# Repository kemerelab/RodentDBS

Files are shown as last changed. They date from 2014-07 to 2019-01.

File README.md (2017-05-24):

Rodent Stimulation Module Project
=========

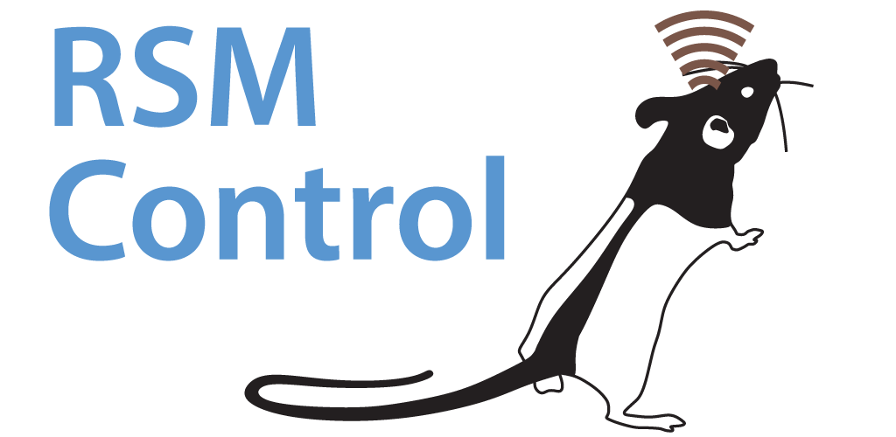
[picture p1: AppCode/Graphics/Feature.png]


Rodent-scale open source programmable constant current deep brain stimulation system. Runs on a
low power MSP430 microcontroller from Texas Instrumnents. Interfaces with an Android app using
Near Field Communication (NFC).

   - The [Firmware/](Firmware/) directory contains the code which runs on the MSP430. 
   - The [AppCode/](AppCode/) directory contains the Android Studio project and code for the
     NFC controller app.
   - The [PCBs/](PCBs/) directory contains the design files for the printed circuit board
     hardware.

#### Physical Size of Devices In Action
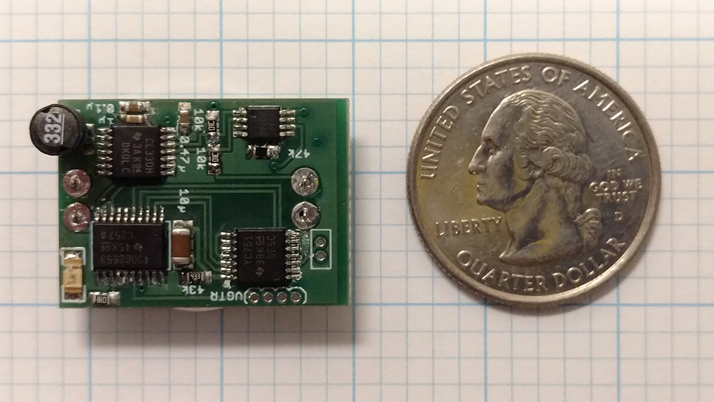
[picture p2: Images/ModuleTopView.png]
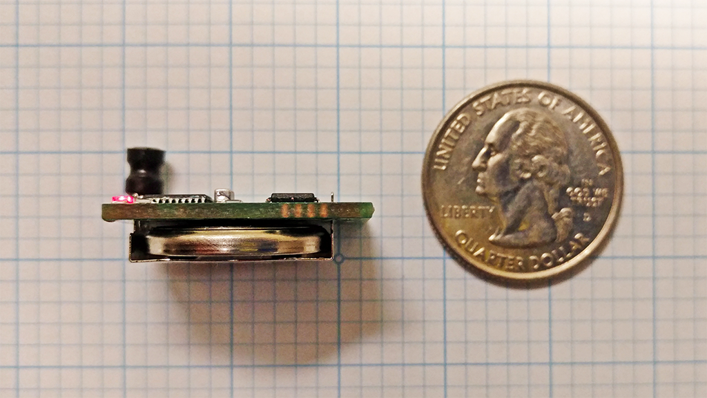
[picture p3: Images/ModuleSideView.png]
 

The most recent version of the hardware is about 1/4" thick including a CR2032 battery, and a
little larger than a quarter in footprint. Battery life is about 200 hours. In photos above,
major grid is 1/2".

#### Biphasic Constant Current Stimulation
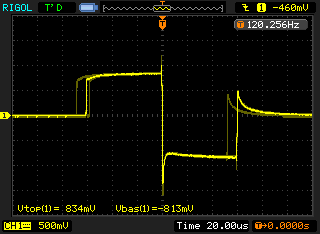
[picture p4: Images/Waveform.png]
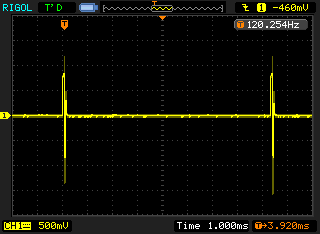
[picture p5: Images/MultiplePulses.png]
 

Current measurements (voltage over the series 10 K resistor)
for a 90 µA, 60 µs, 120 Hz stimulation settings.

Developed by members of the [Kemere Lab](http://rnel.rice.edu) at Rice University. This work
was supported by the National Science Foundation (NSF CAREER Award CBET-1351692) and Texas
Instruments, Inc. Any opinions, findings, and conclusions or recommendations expressed in this
material are those of the author(s) and do not necessarily reflect the views of the National
Science Foundation.



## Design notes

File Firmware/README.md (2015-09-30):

### Firmware for the Rodent Stimulation Module Project

The most recent version of the firmware is [FirmwareCode/](FirmwareCode/). Firmware
for older, non NFC-controlled devices is in [Old_NoNFC/](Old_NoNFC).
[BoardTest/](BoardTest/) is a simple program which blinks the LED to test whether the
MSP430 is programming correctly (in the future, we'll add tests of the other devices on board
to this code).

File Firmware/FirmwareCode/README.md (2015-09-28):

## Overview

The firmware runs on an MSP430G2553. This is a low power TI microcontroller. 

## Estimating power consumption 

**MSP430**
In sleep mode, we can only go to LPM0 because the stimulation counter is using 
the DCO to generate a 1 MHz SMCLK. Unclear is how often we are in active mode.

   - Active power  = ~70 uA
   - Sleep (LPM0) = ~35 uA

**Battery voltage sampling**
The MSP430 ADC10 will consume something like 800 uA when it's turned on, but we sample only
once per minute, so expect not to have significant contribution to power consumption.

**I2C current**
I2C pullup resistors should not be causing signifant current use as I/Os should be high-Z
except during data transmission.

**Power LED**
We're using PWM and flashing, so we're active for only PWM rate * On time.  An on PWM level of
20% and a 25 ms flash every second implies a scaling of 0.2 * 0.025 = 0.005. If VDD is 3 V, and
the on voltage of the (red) LED is 1.8 V, with a 1 K current limiting resistor, our on current
is 1.2 mA. So expect consumption is 6 uA.

   - LED power = 6 uA

**DS4432**
Unfortunately, the current source has to be on all the time because turning on and off would
essentially take the entire inter-pulse period (due to I2C transmission time). Hard to tell
from the data sheet exactly what power will be. Max is 150 uA, but we expect a bit less.

   - DS4432 power = 100 uA

**TS3A4751** (switch matrix)
The switch matrix is fairly efficient, though it, like the DS4432, is powered constantly. We
expect supply current to be close to 3.6 V table values.

  - TS3A4751 power = 1 uA

**RF430** (NFC power)
The RF430 will actually work much better with a 3V supply than a 3.6V supply because the NFC
field provides a 3V power source. In that regime, using NFC to read data is essentially free,
and only during periods when the device is communicating with the MSP430 does it consume power.
When we read data, we are read/writing in the following pattern:
  (1) check status (i.e., address  + 2 bytes = 2 bytes)
  (2) potentially clear interrupts (address + 4 bytes = 5 bytes)
  (3) disable RF (address + 4 bytes = 5 bytes)
  (4) read stim parameters (address + 2 + 6 = 9 bytes)
  (5) re-enable RF (5 bytes)
This is a total of ~26 bytes worth of I2C at 400 kHz, which corresponds to 520 us.
Writing is the same except that the data transmission stage is 21 instead of 6 bytes, so 820
us. Currently, the firmware is set to write 3x/second and read once per 30 seconds or on
demand. So that suggests that the device will be active for 2.5 ms per second. Active power is
250 uA and "passive" power is 40 uA (though we could lower to 15 uA by disabling RF). So we
expect passive mode to dominate, or ~40 uA consumption.

  - RF430 power = 40 uA

  - Total power assuming active mode dominates for MS430 = 217 uA
  - Total power assuming passive mode dominates for MS430 = 182 uA

According to Energizer, we can expect a CR2032 to drop below 2.7 V (the rated minimum voltage
for the DS4432 current source) after about 1000 hours at a constant draw of 0.19 mA. So we
expect our battery life to be ~900 hours, which would be a month. However, in practice, we're
seeing something less than that!?

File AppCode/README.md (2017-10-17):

### RSMControl - An Android app for controlling the Rodent Stimulation Moduke using NFC

### Screenshots

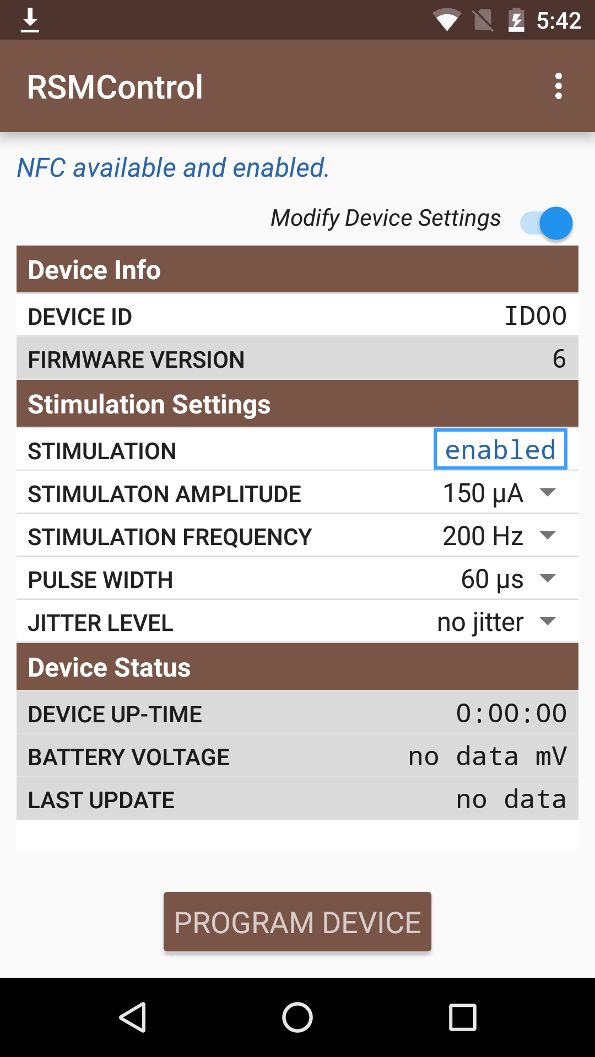
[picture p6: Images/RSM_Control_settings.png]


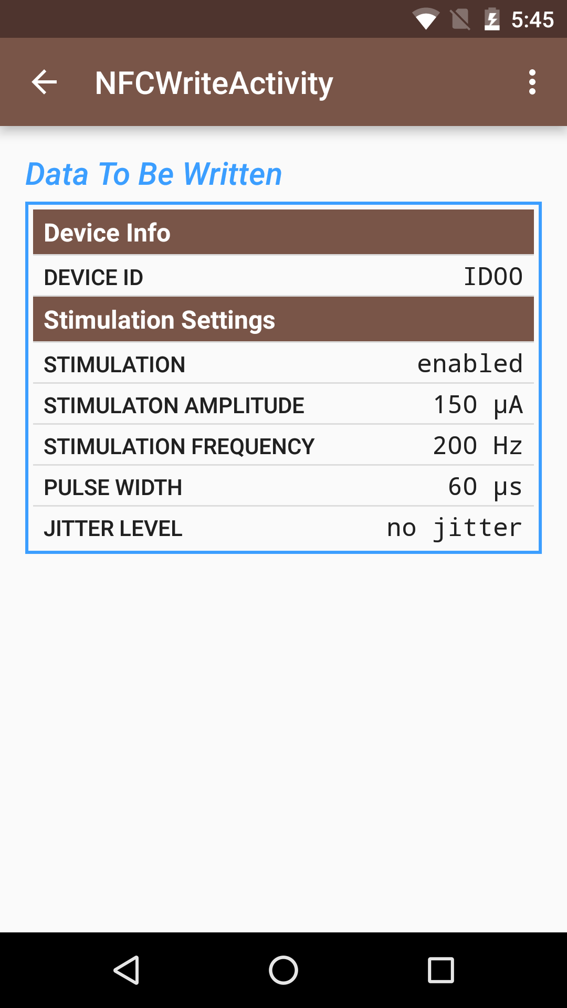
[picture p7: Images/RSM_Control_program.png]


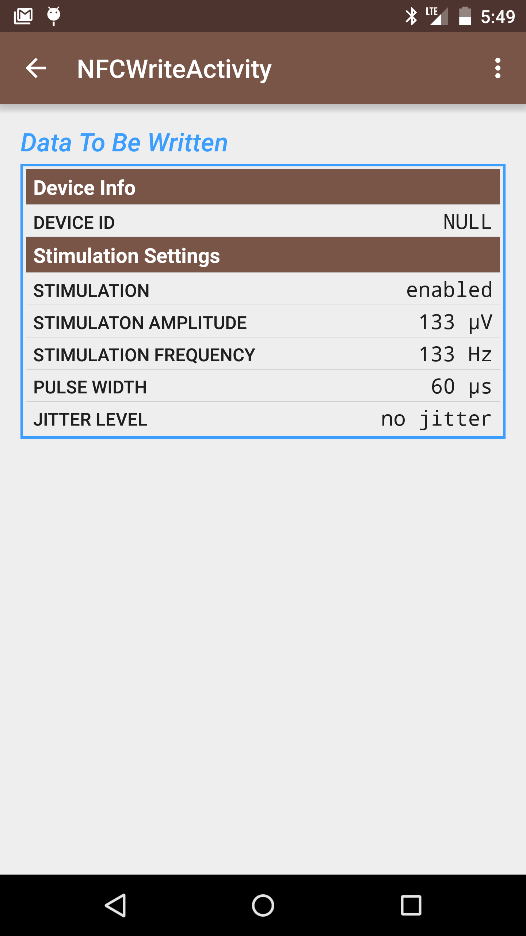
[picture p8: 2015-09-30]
AppCode/Graphics/AndroidAppScreenshot2.png

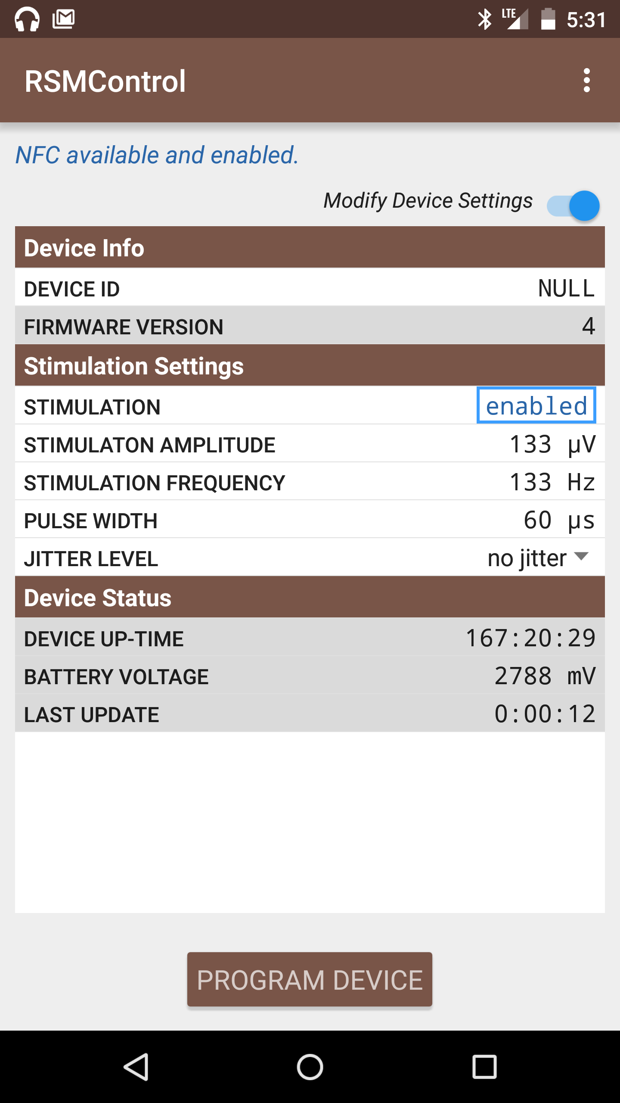
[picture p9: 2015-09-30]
AppCode/Graphics/AndroidAppScreenshot.png

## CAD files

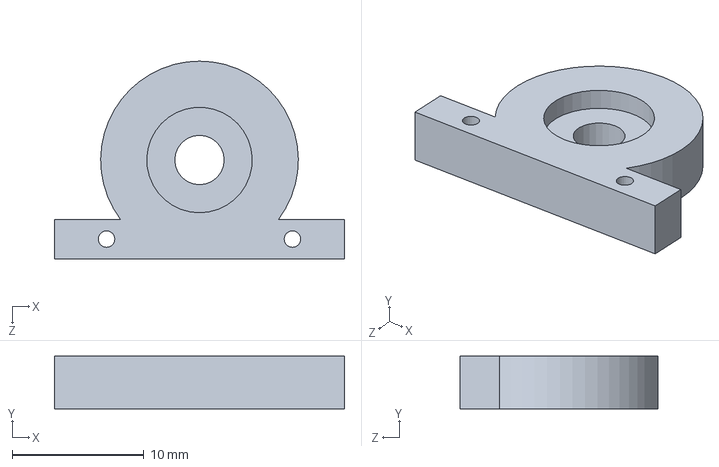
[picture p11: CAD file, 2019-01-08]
Headcap Assembly Files/cone_stereotax_adapter.SLDPRT
22.0 x 4.00 x 15.0 mm

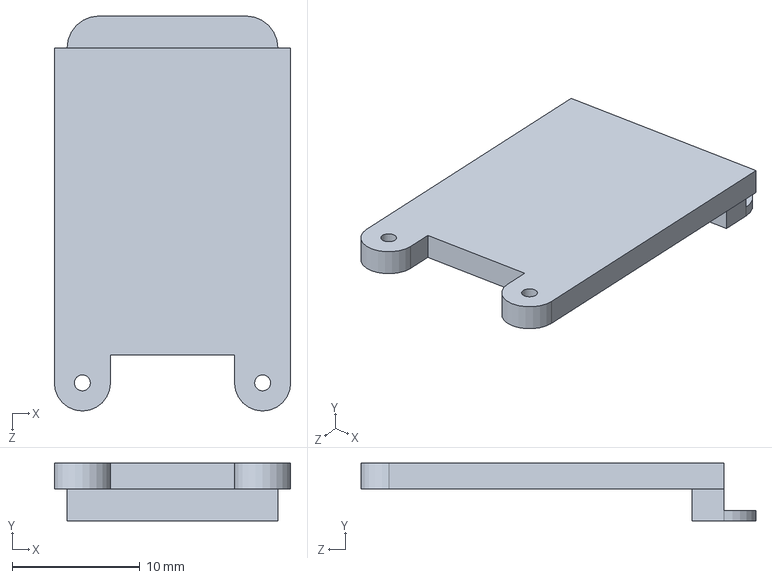
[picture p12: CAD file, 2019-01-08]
Headcap Assembly Files/lid_no_stimulator.SLDPRT
18.5 x 4.50 x 30.9 mm

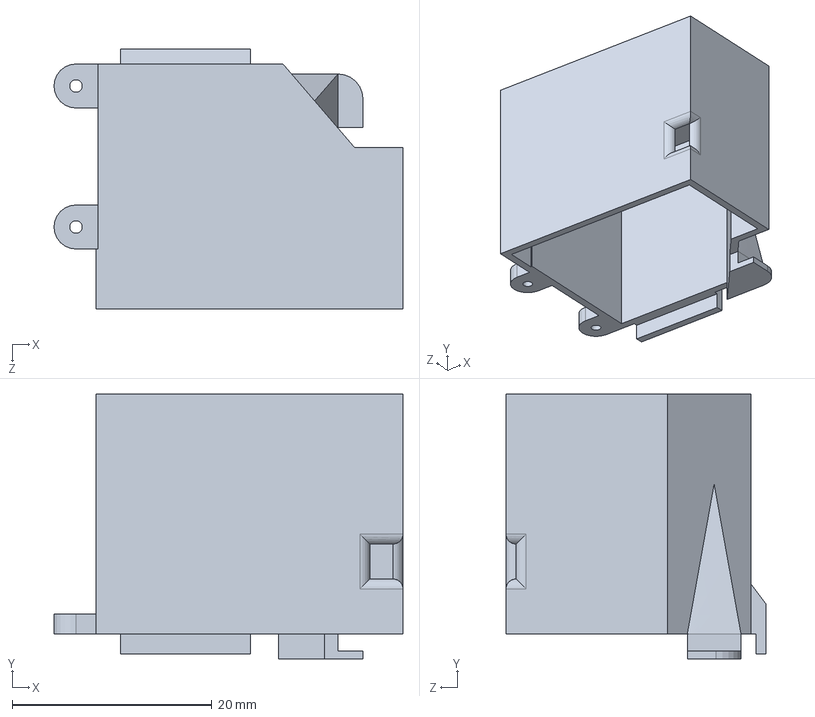
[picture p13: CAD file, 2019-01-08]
Headcap Assembly Files/lid_for_stimulator.SLDPRT
34.9 x 26.5 x 26.0 mm

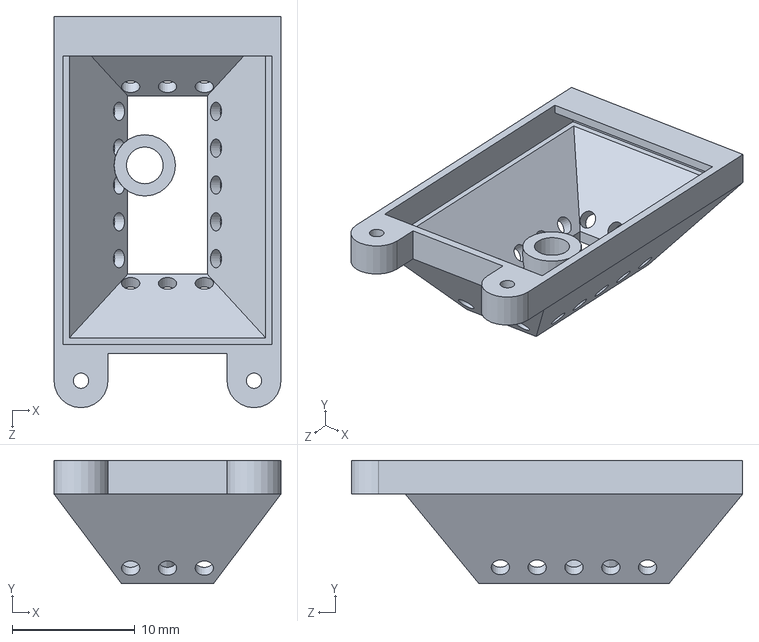
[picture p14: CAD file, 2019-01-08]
Headcap Assembly Files/plastics_one_concentric_cone.SLDPRT
18.5 x 10.0 x 31.9 mm

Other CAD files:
Headcap Assembly Files/cone_stereotax_adapter.STL
Headcap Assembly Files/lid_for_stimulator.STL
Headcap Assembly Files/lid_no_stimulator.STL
Headcap Assembly Files/plastics_one_concentric_cone.STL

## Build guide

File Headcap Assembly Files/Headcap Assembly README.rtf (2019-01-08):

Mounting the stimulator to the rodent consists of 2 parts there is a cone that is attached to the rodent skull, and a lid that will cover the electrode ports of the cone, or hold the stimulator. The cone fits a plastics one concentric 22 gauge 2 channel electrode.

The shaft for the cone must be tapped with an 8-32 thread to fit fit the electrode. The electrode is fixed to the cone body by superglue in the threading to keep the electrode from shifting while disconnecting and reconnecting the plastics one electrode adapter.

The cone electrode assembly is lowered stereotaxically using the stereotax adapter. 0-80 screws attach the adapter to the cone. The adapter screws into the arm of the stereotax. The cone is fixed to the rodent skull with dental acryllic, bone screws, and bone cement.

The stimulator printed circuit board fits vertically into the lid with the inductive NFC antennae towards the top of the lid for programming. The assembly with electrode, lid, and circuit board are illustradted in the render.

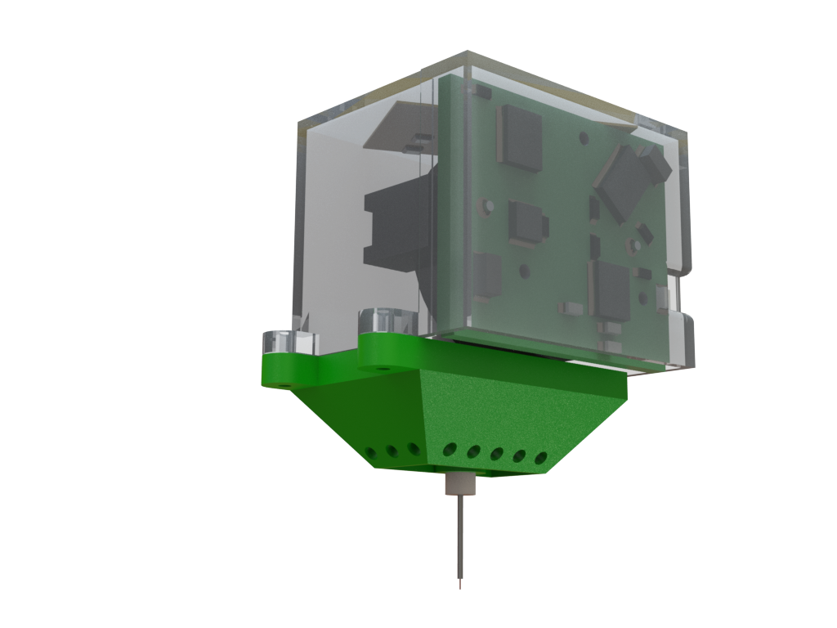
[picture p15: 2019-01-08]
Headcap Assembly Files/Stimulator_assembly_render.png

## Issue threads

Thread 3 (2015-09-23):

Android app preferences

ckemere, 2015-09-23:
Should be able to set value of current limiting resistor. Also nice to "reveal advanced options" (i.e. random stim, maybe something about battery life, logging, Google log in

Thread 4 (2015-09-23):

Have firmware log battery voltage in excess nfc space

ckemere, 2015-09-23:
A timestamp and battery voltage  will allow us to accurately estimate battery life, though it will require logging to get the data off.

ckemere, 2015-10-01:
This is implemented but not tested in recent firmware version. The challenge is that android by default will write ndef short records if payload is small, so firmware has to check and potentially  update essentially the whole record with each write rather than just the incremental update.

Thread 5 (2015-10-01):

"modify settings" switch starts out in wrong state

ckemere, 2015-10-01:
Should be inactivated to start.

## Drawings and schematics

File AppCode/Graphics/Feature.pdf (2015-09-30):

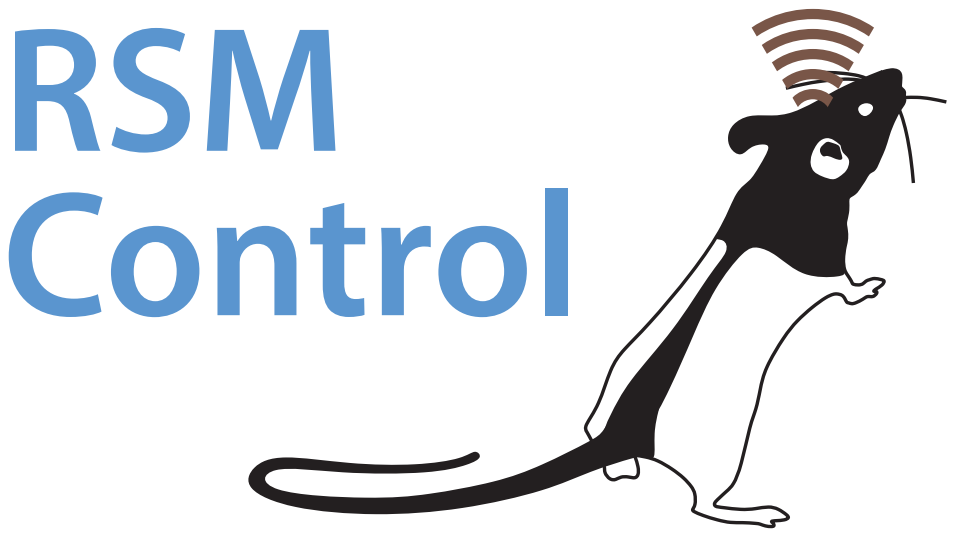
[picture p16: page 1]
RSM Control

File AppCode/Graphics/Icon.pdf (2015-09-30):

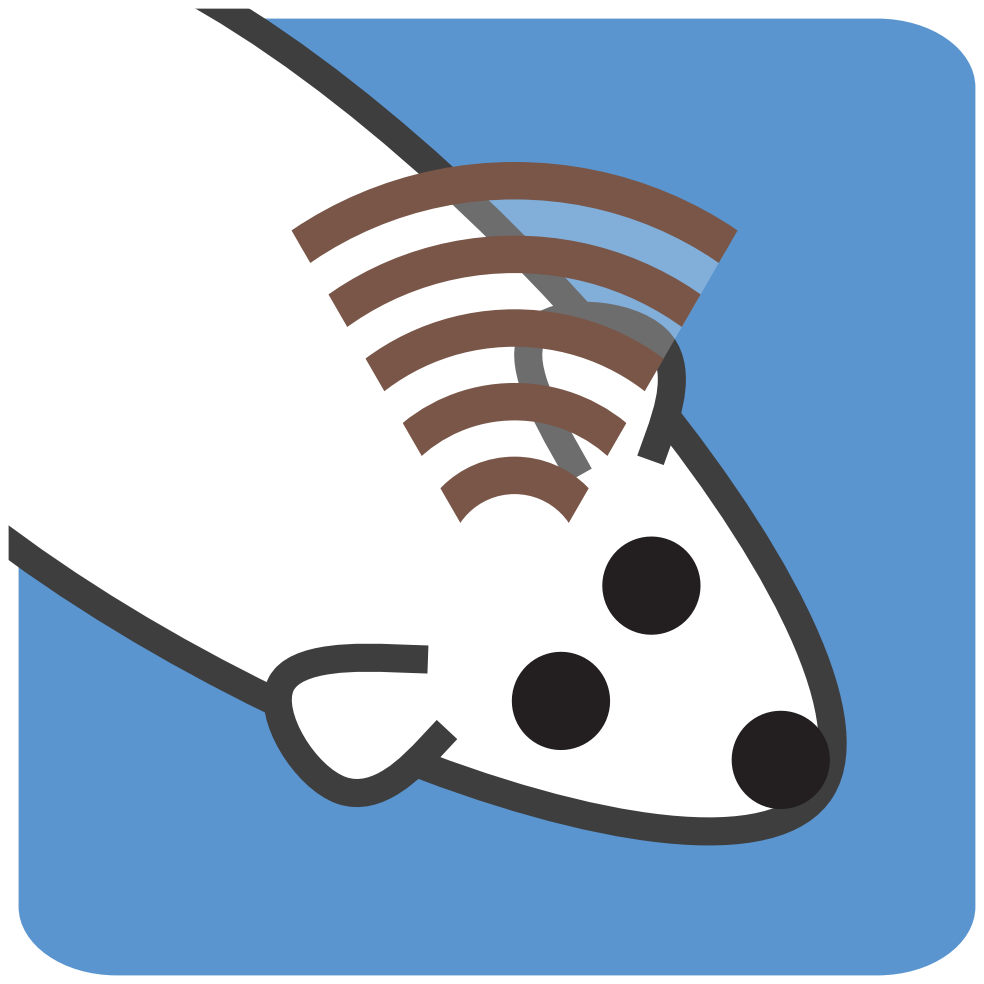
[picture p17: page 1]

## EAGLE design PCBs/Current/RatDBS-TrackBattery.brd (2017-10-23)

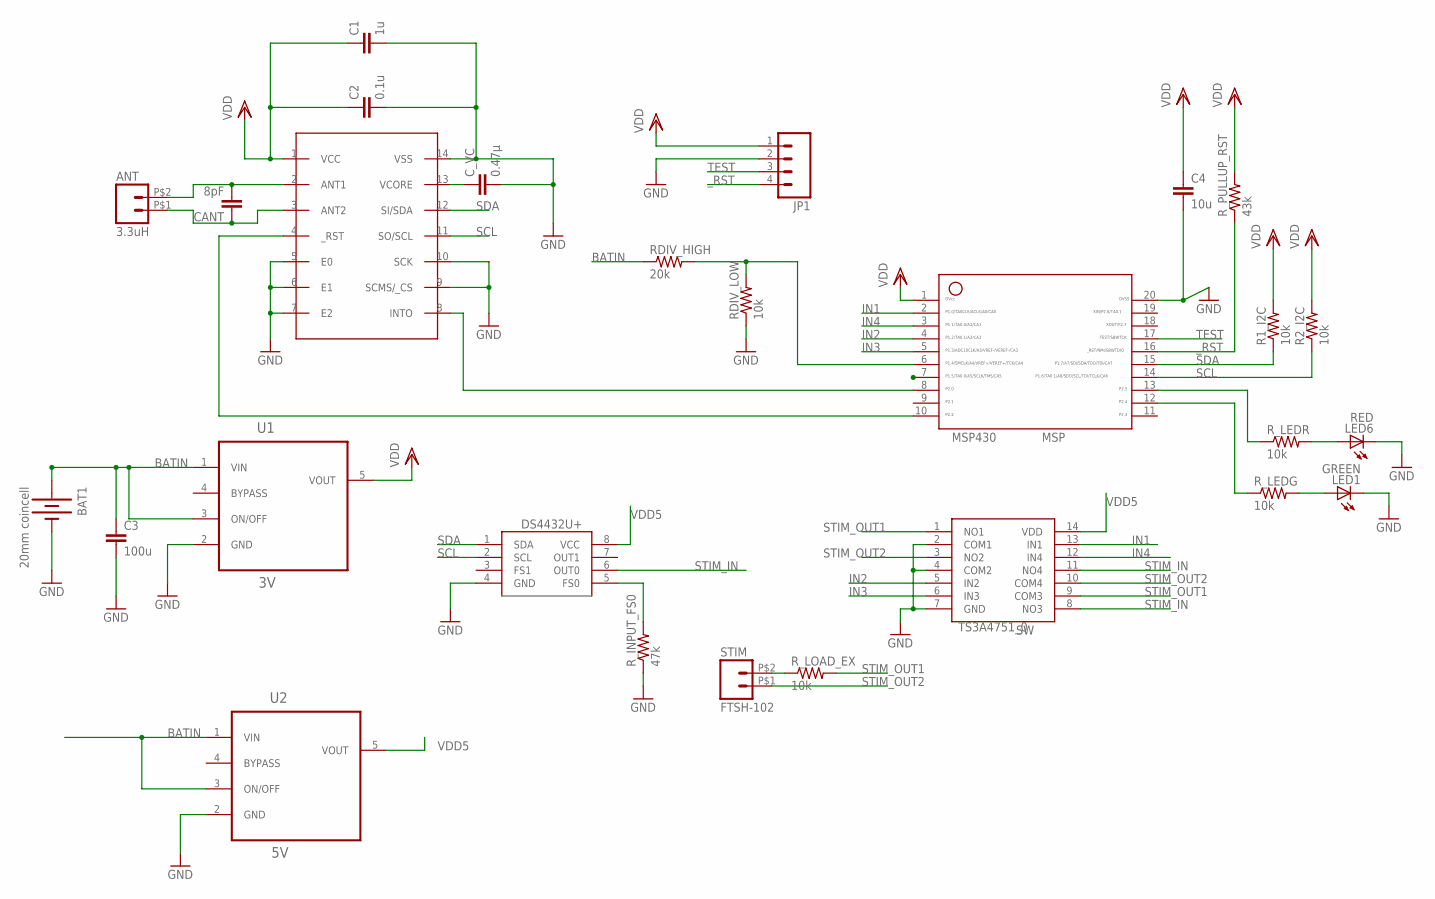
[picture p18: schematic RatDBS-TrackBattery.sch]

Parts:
ANT: 3.3uH; FTSH-102-DH
BAT1: 20mm coincell; BATTCOM_20MM_PLASTIC_STUDS
C1: 1u; C0603
C2: 0.1u; C0603
C3: 100u; C1206
C4: 10u; C1206
CANT: 8pF; C0603
C_VC: 0.47µ; C0603
DS4432U+: DS4432U+; 8_PIN
JP1: M041.27MM; 1X04-1.27MM
LED1: GREEN; LED-1206
LED6: RED; LED-1206
MSP430: MSP; 20_PIN
R1_I2C, R2_I2C: 10k; R0603
RDIV_HIGH: 20k; R0603
RDIV_LOW: 10k; R0603
R_INPUT_FS0: 47k; R0603
R_LEDG: 10k; R0603
R_LEDR: 10k; R0603
R_LOAD_EX: 10k; R0603
R_PULLUP_RST: 43k; R0603
STIM: FTSH-102; FTSH-102-DH
TS3A4751_0: SW; 14_PIN
U1: 3V; SOT95P280X145-5N
U2: 5V; SOT95P280X145-5N
U$1: NFC; PW_R-PDSO-G14

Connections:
BATIN: BAT1.1 (+), C3.1, RDIV_HIGH.1, U1.1 (VIN), U1.3 (ON/OFF), U2.1 (VIN), U2.3 (ON/OFF)
GND: BAT1.2 (-), C1.2, C2.2, C3.2, C4.2, C_VC.2, DS4432U+.4 (GND), JP1.2, LED1.C, LED6.C, MSP430.20, RDIV_LOW.1, R_INPUT_FS0.1, TS3A4751_0.2 (COM1), TS3A4751_0.4 (COM2), TS3A4751_0.7 (GND), U1.2 (GND), U2.2 (GND), U$1.5 (E0), U$1.6 (E1), U$1.7 (E2), U$1.9 (SCMS/_CS), U$1.10 (SCK), U$1.14 (VSS)
IN1: MSP430.2, TS3A4751_0.13 (IN1)
IN2: MSP430.4, TS3A4751_0.5 (IN2)
IN3: MSP430.5, TS3A4751_0.6 (IN3)
IN4: MSP430.3, TS3A4751_0.12 (IN4)
unnamed: C_VC.1, U$1.13 (VCORE)
unnamed: ANT.P$2 (2), CANT.2, U$1.2 (ANT1)
unnamed: MSP430.8, U$1.8 (INTO)
unnamed: R_LOAD_EX.1, STIM.P$2 (2)
unnamed: MSP430.13, R_LEDR.1
unnamed: MSP430.10, U$1.4 (_RST)
unnamed: DS4432U+.5 (FS0), R_INPUT_FS0.2
unnamed: LED6.A, R_LEDR.2
unnamed: MSP430.6, RDIV_HIGH.2, RDIV_LOW.2
unnamed: MSP430.12, R_LEDG.1
unnamed: ANT.P$1 (1), CANT.1, U$1.3 (ANT2)
unnamed: LED1.A, R_LEDG.2
SCL: DS4432U+.2 (SCL), MSP430.14, R2_I2C.1, U$1.11 (SO/SCL)
SDA: DS4432U+.1 (SDA), MSP430.15, R1_I2C.1, U$1.12 (SI/SDA)
STIM_IN: DS4432U+.6 (OUT0), TS3A4751_0.8 (NO3), TS3A4751_0.11 (NO4)
STIM_OUT1: R_LOAD_EX.2, TS3A4751_0.1 (NO1), TS3A4751_0.9 (COM3)
STIM_OUT2: STIM.P$1 (1), TS3A4751_0.3 (NO2), TS3A4751_0.10 (COM4)
TEST: JP1.3, MSP430.17
VDD: C1.1, C2.1, C4.1, JP1.1, MSP430.1, R1_I2C.2, R2_I2C.2, R_PULLUP_RST.2, U1.5 (VOUT), U$1.1 (VCC)
VDD5: DS4432U+.8 (VCC), TS3A4751_0.14 (VDD), U2.5 (VOUT)
_RST: JP1.4, MSP430.16, R_PULLUP_RST.1

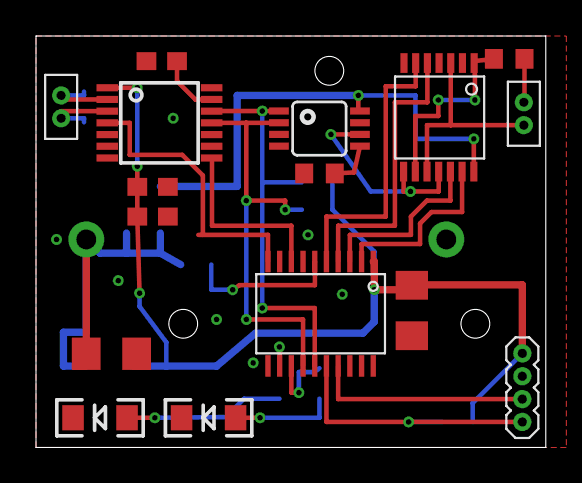
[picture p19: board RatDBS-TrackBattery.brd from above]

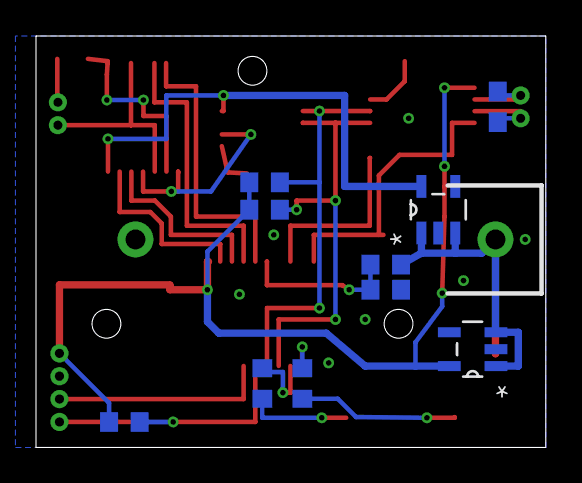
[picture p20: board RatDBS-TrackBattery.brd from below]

Board: 2 copper layers, 28.3 x 22.9 mm, 27 parts (11 on the bottom side), 27 nets.

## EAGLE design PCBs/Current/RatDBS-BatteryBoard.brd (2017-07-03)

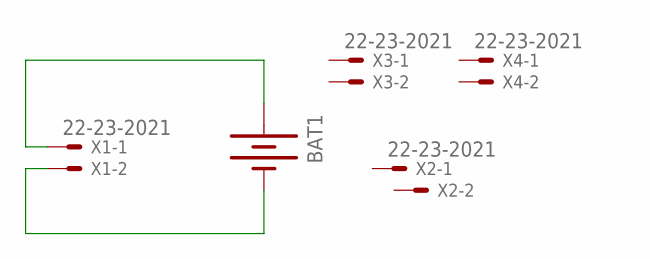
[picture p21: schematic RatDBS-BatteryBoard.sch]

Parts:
BAT1: BATTERY; BATTCOM_20MM_PLASTIC_STUDS
X1, X2, X3, X4: 22-23-2021

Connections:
BATIN: BAT1.1 (+), X1.1
GND: BAT1.2 (-), X1.2

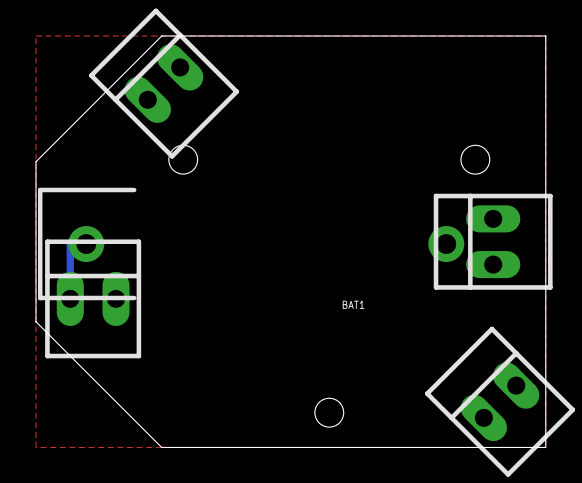
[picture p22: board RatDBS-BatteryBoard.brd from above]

Board: 2 copper layers, 28.3 x 22.9 mm, 5 parts (0 on the bottom side), 2 nets.

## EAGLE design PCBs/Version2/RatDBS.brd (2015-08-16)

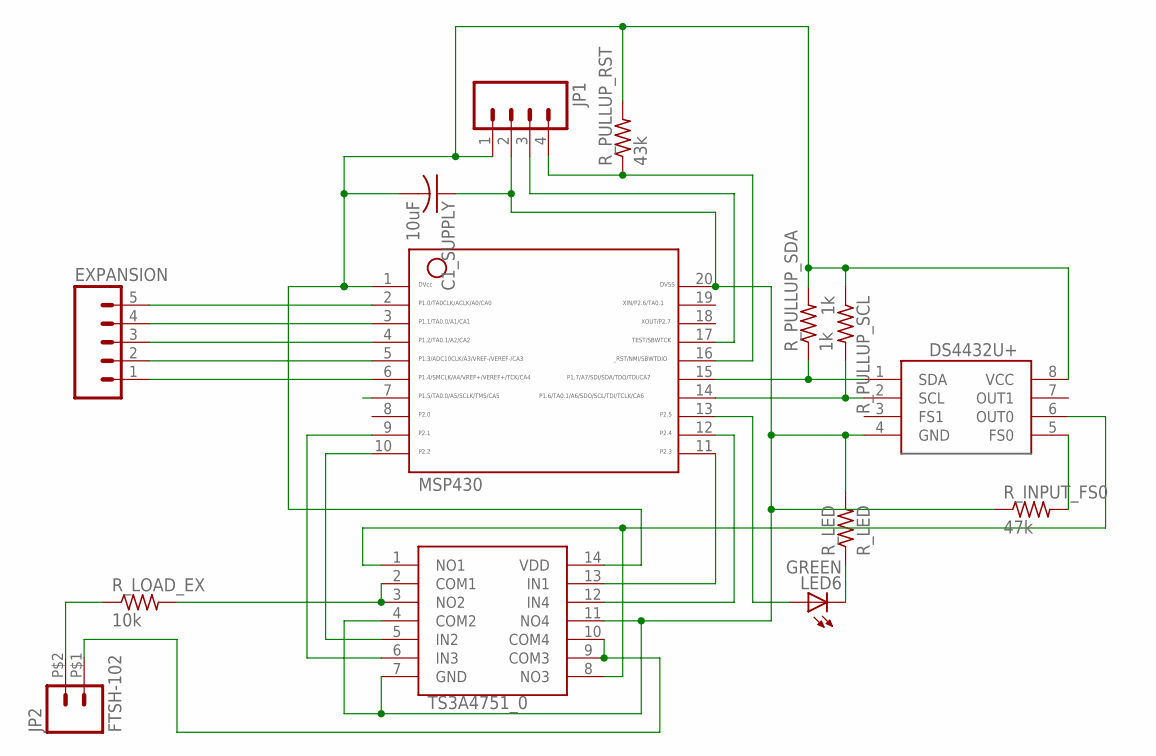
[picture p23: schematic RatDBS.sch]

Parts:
C1_SUPPLY: 10uF; C0603
DS4432U+: DS4432U+; 8_PIN
EXPANSION: M051.27MM; 1X05-1.27MM
JP1: M041.27MM; 1X04-1.27MM
JP2: FTSH-102; FTSH-102-DH
LED6: GREEN; LED-1206
MSP430: MSP430; 20_PIN
R_INPUT_FS0: 47k; R0603
R_LED: R_LED; R0603
R_LOAD_EX: 10k; R0603
R_PULLUP_RST: 43k; R0603
R_PULLUP_SCL: 1k; R0603
R_PULLUP_SDA: 1k; R0603
TS3A4751_0: TS3A4751; 14_PIN

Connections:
CURRENT0: DS4432U+.6 (OUT0), TS3A4751_0.1 (NO1), TS3A4751_0.8 (NO3)
GND: C1_SUPPLY.1, DS4432U+.4 (GND), JP1.2, MSP430.20, R_INPUT_FS0.1, R_LED.2, TS3A4751_0.4 (COM2), TS3A4751_0.7 (GND), TS3A4751_0.11 (NO4)
IN1: MSP430.11, TS3A4751_0.13 (IN1)
IN2_0: MSP430.10, TS3A4751_0.5 (IN2)
IN3_0: MSP430.9, TS3A4751_0.6 (IN3)
IN4: MSP430.12, TS3A4751_0.12 (IN4)
LOAD1_0: R_LOAD_EX.2, TS3A4751_0.2 (COM1), TS3A4751_0.3 (NO2)
LOAD2_0: JP2.P$1 (1), TS3A4751_0.9 (COM3), TS3A4751_0.10 (COM4)
unnamed: DS4432U+.2 (SCL), MSP430.14, R_PULLUP_SCL.2
unnamed: DS4432U+.1 (SDA), MSP430.15, R_PULLUP_SDA.1
unnamed: EXPANSION.1, MSP430.6
unnamed: JP2.P$2 (2), R_LOAD_EX.1
unnamed: LED6.A, MSP430.13
unnamed: EXPANSION.2, MSP430.5
unnamed: DS4432U+.5 (FS0), R_INPUT_FS0.2
unnamed: LED6.C, R_LED.1
unnamed: EXPANSION.3, MSP430.4
unnamed: EXPANSION.4, MSP430.3
unnamed: EXPANSION.5, MSP430.2
TEST: JP1.3, MSP430.17
VDD: C1_SUPPLY.2, DS4432U+.8 (VCC), JP1.1, MSP430.1, R_PULLUP_RST.2, R_PULLUP_SCL.1, R_PULLUP_SDA.2, TS3A4751_0.14 (VDD)
_RST: JP1.4, MSP430.16, R_PULLUP_RST.1

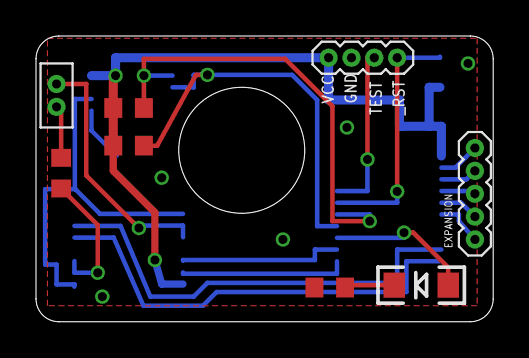
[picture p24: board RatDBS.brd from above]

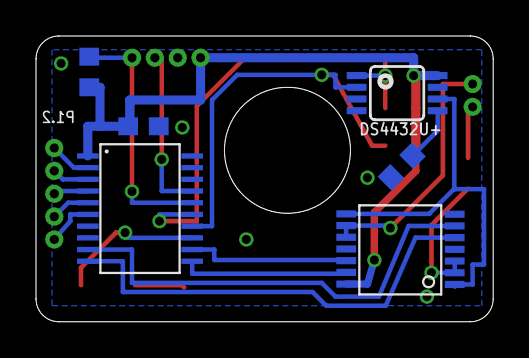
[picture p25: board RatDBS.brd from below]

Board: 2 copper layers, 25.4 x 15.9 mm, 14 parts (6 on the bottom side), 22 nets.

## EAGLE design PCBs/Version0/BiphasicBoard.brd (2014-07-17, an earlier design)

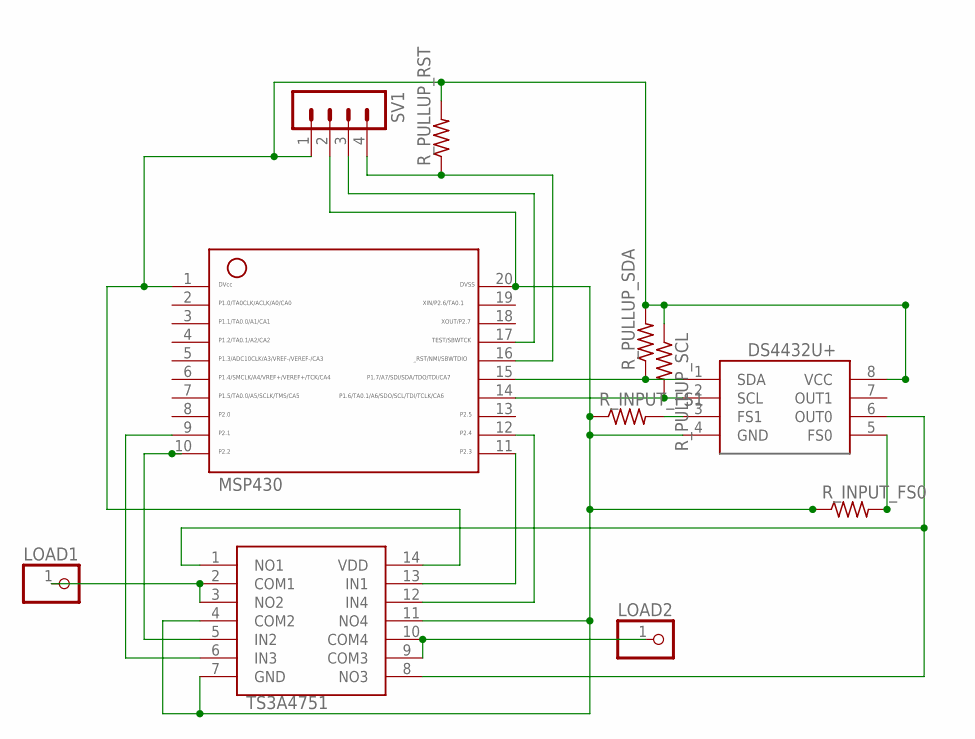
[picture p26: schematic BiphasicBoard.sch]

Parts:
DS4432U+: DS4432U+; 8_PIN
LOAD1, LOAD2: PINHD-1X1; 1X01
MSP430: MSP430; 20_PIN
R_INPUT_FS0, R_INPUT_FS1: R-US_R0603; R0603
R_PULLUP_RST: R-US_R0603; R0603
R_PULLUP_SCL: R-US_R0603; R0603
R_PULLUP_SDA: R-US_R0603; R0603
SV1: MA04-1
TS3A4751: TS3A4751; 14_PIN

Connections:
CURRENT0: DS4432U+.6 (OUT0), TS3A4751.1 (NO1), TS3A4751.8 (NO3)
GND: DS4432U+.4 (GND), MSP430.20, R_INPUT_FS0.1, R_INPUT_FS1.1, SV1.2, TS3A4751.4 (COM2), TS3A4751.7 (GND), TS3A4751.11 (NO4)
IN1: MSP430.11, TS3A4751.13 (IN1)
IN4: MSP430.12, TS3A4751.12 (IN4)
LOAD1: LOAD1.1, TS3A4751.2 (COM1), TS3A4751.3 (NO2)
LOAD2: LOAD2.1, TS3A4751.9 (COM3), TS3A4751.10 (COM4)
unnamed: DS4432U+.2 (SCL), MSP430.14, R_PULLUP_SCL.2
unnamed: DS4432U+.1 (SDA), MSP430.15, R_PULLUP_SDA.1
unnamed: MSP430.10, TS3A4751.5 (IN2)
unnamed: DS4432U+.5 (FS0), R_INPUT_FS0.2
unnamed: MSP430.9, TS3A4751.6 (IN3)
TEST: MSP430.17, SV1.3
VDD: DS4432U+.8 (VCC), MSP430.1, R_PULLUP_RST.2, R_PULLUP_SCL.1, R_PULLUP_SDA.2, SV1.1, TS3A4751.14 (VDD)
VIA1: DS4432U+.3 (FS1), R_INPUT_FS1.2
_RST: MSP430.16, R_PULLUP_RST.1, SV1.4

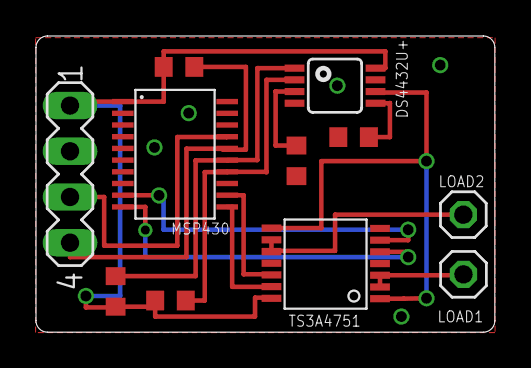
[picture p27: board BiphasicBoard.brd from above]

Board: 2 copper layers, 25.5 x 16.5 mm, 11 parts (0 on the bottom side), 15 nets.

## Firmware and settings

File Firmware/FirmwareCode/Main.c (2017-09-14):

/*
 * Copyright (c) 2015, Caleb Kemere
 * All rights reserved.
 *
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
 * 1. Redistributions of source code must retain the above copyright
 * notice, this list of conditions and the following disclaimer.
 *
 * 2. Redistributions in binary form must reproduce the above copyright
 * notice, this list of conditions and the following disclaimer in the
 * documentation and/or other materials provided with the distribution.
 *
 * 3. Neither the name of the copyright holder nor the names of its
 * contributors may be used to endorse or promote products derived
 * from this software without specific prior written permission.
 *
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
 * --/COPYRIGHT--
 *
 *******************************************************************************
 *
 *                       Rodent Stimulation Module (RSM) Firmware
 *
 * This file contains the main loop for the RSM module. The main loop cycles
 * between 3 phases of stimulation (forward current, reverse current, and inter-
 * stimulation), and additionally performs other monitoring and communication
 * functionality.
 *
 * Resources:
 *  - Uses watchdog timer for general program state control
 *  - Uses Timer A0 for stimulation pulse timing
 *  - Uses PWM/Timer A1 module for display light (and Pin 2.5)
 *  - Uses Pins 1.0-1.3 for control of switch array
 *  - Uses Pins 1.6, 1.7 for I2C ()
 *
*/

#include <msp430.h>
#include "Firmware.h"
#include "Board.h"
#include "BatteryStatus.h"
#include "JitterTable.h"
#include "SwitchMatrix.h"
#include "I2C.h"
#include "NFCInterface.h"
#include "CurrentSource.h"
#include "string.h"


// GLOBALS
volatile uint32_t DeviceMasterClock;
volatile unsigned char KernelWakeupFlag = 0;
// This flag locks the main kernel timer from waking up a subprocess that has slept.

// Initialize the device data. Descriptive - ID and firmware version; Status -
//   uptime, battery voltage, and last update.
volatile DeviceData_t DeviceData = {\
        .ID.idStr = DEFAULT_DEVICE_IDSTR, .ID.firmwareVersion = PROTOCOL_VERSION, \
        .Status.BatteryVoltage = 0, .Status.Uptime = 0, .Status.LastUpdate = 0,\
        .StimParams.Enabled = 0, .StimParams.Period = 7500, \
        .StimParams.Amplitude = 100, .StimParams.PulseWidth = 60,
        .StimParams.JitterLevel = 0, \
        .Status.BatteryVoltage = 0, .Status.Uptime = 0, .Status.LastUpdate = 0};

volatile int StimParamsChanged = 0;

/*
 * State variables for main loop control.
 */
volatile unsigned int CheckBatteryCounter = 50; // start this small so we get an immediate reading
volatile unsigned int ReadNFCDataCounter = READ_NFC_DATA_PERIOD-1;
volatile unsigned int UpdateNFCDataCounter = 200; // start this small so we get an immediate reading


/*
 * We use an LED to monitor device status. In addition to controlling intensity
 * with PWM, we have the LED blink with a very short ON time. There are
 * currently two blinking states, a "stimulation is off" blink at 2 Hz,
 * a "stimulation is on" blink at 1 Hz.
 *
 */
volatile int PowerLEDIntensity = 200; // Out of 1000
volatile unsigned int LEDState = 0;
#define HEARTBEAT_ON 25
unsigned int HeartBeatPattern_StimOff[] = {HEARTBEAT_ON, 1500-HEARTBEAT_ON, HEARTBEAT_ON, 1500-HEARTBEAT_ON}; // (on, off, on, off)
unsigned int HeartBeatPattern_StimOn[] = {HEARTBEAT_ON, 250, HEARTBEAT_ON, 1500 - 2*HEARTBEAT_ON - 250};
unsigned int HeartBeatPattern_Error[] = {HEARTBEAT_ON, 250, HEARTBEAT_ON, 250};
unsigned int *HeartBeatPattern;
volatile unsigned int LEDCounter = HEARTBEAT_ON;


void MasterClockSetup(void){
    TA1CTL = TASSEL_2 + MC_1;  // SMCLK (1 MHz), up mode, enable interrupt
    TA1CCR0 = 1000;            // 1 ms period
    TA1CCTL0 = CCIE;           // CCR0 interrupt enabled

    // Initialize GPIO for status LED
    STATUS_LED_PDIR |= STATUS_LED_PIN;    //initialize Status LED pin as output
    STATUS_LED_PSEL |= STATUS_LED_PIN;    //select Status LED pin as PWM
    TA1CCTL2 = OUTMOD_7;           //CCR2 reset/set
    TA1CCR2 = PowerLEDIntensity;   //pin 2.5 brightness (PWM duty cycle versus TA1CCR0)

    HeartBeatPattern = HeartBeatPattern_Error;
}

inline void KernelSleep(void) {
    KernelWakeupFlag = 0;
    __bis_SR_register(CPUOFF + GIE); // Enter LPM0 w/ interrupts
    KernelWakeupFlag = 1;
}

void main(void)
{
    StimParams_t NewStimParams = { .Enabled = 0, .Period = 7500, \
            .Amplitude = 100, .PulseWidth = 60 };

    int StimParamsChanged = 0;

    WDTCTL = WDTPW + WDTHOLD;                 // Stop WDT

    // Set up system clocks
    BCSCTL1 = CALBC1_8MHZ;   // Set range
    DCOCTL = CALDCO_8MHZ;    // Set DCO step + modulation
    BCSCTL3 |= LFXT1S_2;     // LFXT1 = VLO (~12 kHz)
    BCSCTL2 = DIVS_3;  // Setup SMCLK to be 1 MHz (divide DCO/8)

    // Default - initialize all ports to output
    P1DIR = 0xFF; P2DIR = 0xFF; P3DIR = 0xFF;
    P1OUT = 0; P2OUT = 0; P3OUT = 0;

    I2CSetup();

    BatteryStatusSetup();

    SetupSwitchMatrix();

    NFCInterfaceSetup();

    MasterClockSetup();

    while (1) {

        if ((RF430InterruptTriggered != 0) || (ReadNFCDataCounter == 0 )) {
            if (RF430InterruptTriggered != 0) {
                ClearNFCInterrupts();
                RF430InterruptTriggered = 0;
            }
            if (ReadDeviceParams(&NewStimParams) == 0) { // Successfully read params
                StimParamsChanged = memcmp((unsigned char*)&NewStimParams,
                        (unsigned char*)&(DeviceData.StimParams), sizeof(StimParams_t));

                if (StimParamsChanged != 0) {
                    // NOTE - WE'RE NOT DOING ANY ERROR CHECKING! MAKE SURE PARAMETERS
                    //   ARE ERROR CHECKED BEFORE TRANSMITTING!
                    DeviceData.StimParams.Period = NewStimParams.Period;
                    DeviceData.StimParams.Amplitude = NewStimParams.Amplitude;
                    SetOutputCurrent(DeviceData.StimParams.Amplitude);
                    DeviceData.StimParams.PulseWidth = NewStimParams.PulseWidth;
                    SetPulseIntervals(DeviceData.StimParams.Period, DeviceData.StimParams.PulseWidth);
                    DeviceData.StimParams.JitterLevel = NewStimParams.JitterLevel;
                    SetJitterOffset(DeviceData.StimParams.JitterLevel);
                    DeviceData.StimParams.Enabled = NewStimParams.Enabled;
                    if (DeviceData.StimParams.Enabled > 0) {
                        HeartBeatPattern = HeartBeatPattern_StimOn;
                        EnableStimulation();
                    }
                    else if (DeviceData.StimParams.Enabled == 0) {
                        HeartBeatPattern = HeartBeatPattern_StimOff;
                        DisableStimulation();
                    }
                    DeviceData.Status.LastUpdate = DeviceData.Status.Uptime;
                }
                ReadNFCDataCounter = READ_NFC_DATA_PERIOD-1;
            }
            else { // Device wasn't ready, so try again in 5 ms
                ReadNFCDataCounter = 5;
                HeartBeatPattern = HeartBeatPattern_Error;
            }
            KernelSleep();
        }
        else if (UpdateNFCDataCounter == 0) { // Device wasn't ready, so try again in 5 ms
            if (UpdateDeviceStatus() == 0) {
                UpdateNFCDataCounter = UPDATE_NFC_DATA_PERIOD-1;
            }
            else {
                UpdateNFCDataCounter = 5;
            }
        }
        else if (CheckBatteryCounter == 0) {
            CheckBattery();
            if (DeviceData.Status.BatteryVoltage < 603) {
                STATUS_LED_PDIR = SWAP_LED_PIN;    //set Red LED as output at low voltage
                STATUS_LED_PSEL = SWAP_LED_PIN;
            }
            else {
                STATUS_LED_PDIR = STATUS_LED_PIN;    //set Green LED as output at high volteage
                STATUS_LED_PSEL = STATUS_LED_PIN;
            }
            CheckBatteryCounter = CHECK_BATTERY_PERIOD-1;
        }

        KernelSleep();

    }
}


// Timer A1 interrupt service routine => Assume CCR0 set for 1 ms ticks
#pragma vector=TIMER1_A0_VECTOR
__interrupt void MasterClockISR (void)
{
    static unsigned int SecondCounter = 1000; // should be 1000!

    if (--SecondCounter == 0) {
        DeviceData.Status.Uptime += 1;
        SecondCounter = 1000;
    }

    // Timer variables for each subprocess that runs in main loop
    if (CheckBatteryCounter > 0)
        CheckBatteryCounter--;
    if (UpdateNFCDataCounter > 0)
        UpdateNFCDataCounter--;
    if (ReadNFCDataCounter > 0)
        ReadNFCDataCounter--;

    // Time variable for blinking LED
    LEDCounter--;
    if (LEDCounter == 0) {
        if ((++LEDState & 0x01) == 0)
            TA1CCR2 = PowerLEDIntensity;   //pin 2.5 brightness (PWM duty cycle versus TA1CCR0)
        else
            TA1CCR2 = 0;   //pin 2.5 brightness (PWM duty cycle versus TA1CCR0)

        LEDState &= 0x03; // faster than checking length
        LEDCounter = HeartBeatPattern[LEDState];
    }

    if (KernelWakeupFlag == 0) { // If the master loop has gone to sleep then wake it up
        __bic_SR_register_on_exit(CPUOFF);
    }

}

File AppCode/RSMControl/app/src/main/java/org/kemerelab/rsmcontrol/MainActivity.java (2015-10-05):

package org.kemerelab.rsmcontrol;

import org.ndeftools.Message;
import org.ndeftools.Record;
import org.ndeftools.externaltype.ExternalTypeRecord;
import org.ndeftools.util.activity.NfcReaderActivity;

import android.app.AlertDialog;
import android.content.Context;
import android.content.DialogInterface;
import android.content.Intent;
import android.graphics.Color;
import android.os.Bundle;
import android.util.Log;
import android.view.Gravity;
import android.view.LayoutInflater;
import android.view.Menu;
import android.view.MenuItem;
import android.view.View;
import android.view.inputmethod.InputMethodManager;
import android.widget.AdapterView;
import android.widget.EditText;
import android.widget.ListView;
import android.widget.NumberPicker;
import android.widget.Switch;
import android.widget.TextView;
import android.widget.Toast;


public class MainActivity extends NfcReaderActivity implements AdapterView.OnItemClickListener, RSMDeviceInfoListAdapter.RSMDeviceInfoSpinnerSelectionListener {


    static final String RSM_DEVICE_STRUCTURE = "rsmDevice";
    static final String EDITTOGGLESTATE = "editToggleState";
    static final String NDEF_DATA_TO_BE_WRITTEN = "NDEF_Data";

    RSMDevice rsmDevice;

    public enum NFCAvalability {
        UNINITIALIZED, NOT_AVAIALBLE, AVAILABLE_NOT_ENABLED, AVAILABLE_ENABLED
    }

    NFCAvalability nfcAvalability = NFCAvalability.UNINITIALIZED;

    private Boolean editingDeviceInfo = false;

    @Override
    public void onCreate(Bundle savedInstanceState) {
        super.onCreate(savedInstanceState);

        if (savedInstanceState != null) {
            // Restore value of members from saved state
            rsmDevice = savedInstanceState.getParcelable(RSM_DEVICE_STRUCTURE);
            editingDeviceInfo = savedInstanceState.getBoolean(EDITTOGGLESTATE);

        } else {
            // Probably initialize members with default values for a new instance
            rsmDevice = new RSMDevice();

        }

        setContentView(R.layout.activity_main);
        Switch s = (Switch) findViewById(R.id.editToggleSwitch);
        s.setChecked(editingDeviceInfo);
        updateStatus(nfcAvalability); // Calls updateDeviceInfoEditState(), which calls updateDeviceInfo()

        // lets start detecting NDEF message using foreground mode
        setDetecting(true);
    }

    @Override
    public void onSaveInstanceState(Bundle savedInstanceState) {
        savedInstanceState.putParcelable(RSM_DEVICE_STRUCTURE, rsmDevice);
        savedInstanceState.putBoolean(EDITTOGGLESTATE,editingDeviceInfo);
        super.onSaveInstanceState(savedInstanceState);
    }

//    @Override
//    protected void onRestoreInstanceState(Bundle savedInstanceState) {
//        super.onRestoreInstanceState(savedInstanceState);
//        rsmDevice = savedInstanceState.getParcelable(MainActivity.RSM_DEVICE_STRUCTURE);
//    }

    @Override
    public boolean onCreateOptionsMenu(Menu menu) {
        // Inflate the menu; this adds items to the action bar if it is present.
        getMenuInflater().inflate(R.menu.menu_main, menu);
        return true;
    }

    @Override
    public boolean onOptionsItemSelected(MenuItem item) {
        // Handle action bar item clicks here. The action bar will
        // automatically handle clicks on the Home/Up button, so long
        // as you specify a parent activity in AndroidManifest.xml.
        int id = item.getItemId();

        //noinspection SimplifiableIfStatement
        if (id == R.id.action_settings) {
//            Intent intent = new Intent(this, SettingsActivity.class);
//            startActivity(intent);
//
//            return true;
        }

        return super.onOptionsItemSelected(item);
    }

    public void toast(String message) {
        Toast toast = Toast.makeText(this, message, Toast.LENGTH_LONG);
        toast.setGravity(Gravity.CENTER_HORIZONTAL | Gravity.CENTER_VERTICAL, 0, 0);
        toast.show();
    }

    public void onProgramButtonClicked (View view) {
        Intent intent = new Intent(this, NFCWriteActivity.class);
        intent.putExtra(NDEF_DATA_TO_BE_WRITTEN, rsmDevice.getDeviceInfoAsByteArray());
        intent.putExtra(RSM_DEVICE_STRUCTURE, rsmDevice);
        startActivity(intent);
    }

    public void updateStatus(NFCAvalability nfcAvalability) {
        TextView t = (TextView) findViewById(R.id.statusTextView);
        if ( t!= null) {
            switch (nfcAvalability) {
                case NOT_AVAIALBLE:
                    t.setText(getString(R.string.noNfcMessage));
                    t.setTextColor(getResources().getColor(R.color.LightRed));
                    break;
                case AVAILABLE_NOT_ENABLED:
                    t.setText(getString(R.string.nfcAvailableDisabled));
                    t.setTextColor(getResources().getColor(R.color.LightRed));
                    break;
                case AVAILABLE_ENABLED:
                    t.setText(getString(R.string.nfcAvailableEnabled));
                    t.setTextColor(getResources().getColor(R.color.DarkBlue));
                    break;
                default:
                    t.setText("Unknown state");
            }
        }
        Log.d("update", "update Status");
        updateDeviceInfoEditState();
    }

    public void updateDeviceInfoEditState() {
        ListView s = (ListView) findViewById(R.id.deviceInfoListView);
        if (editingDeviceInfo)
            s.setBackgroundColor(Color.WHITE);
        else {
            if (nfcAvalability == NFCAvalability.AVAILABLE_ENABLED)
                s.setBackgroundColor(getResources().getColor(R.color.BackgroundLightGray));
            else
                s.setBackgroundColor(getResources().getColor(R.color.BackgroundLightRed));
        }
        updateDeviceDisplay();
    }

    public void onEditSwitchToggled (View view) {
        if (((Switch) view).isChecked())
            editingDeviceInfo = true;
        else {
            editingDeviceInfo = false;
        }
        updateDeviceInfoEditState();
    }


    public void updateDeviceDisplay() {
        ListView lv = (ListView) findViewById(R.id.deviceInfoListView);
        RSMDeviceInfoListAdapter devAdapter = new RSMDeviceInfoListAdapter(this,
                rsmDevice.getDeviceInfoList(this, true), false, editingDeviceInfo);
        lv.setAdapter(devAdapter);
        lv.setOnItemClickListener(this);
        devAdapter.setSpinnerListener(this);
    }
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

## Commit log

2014-05-19 Initial RatDBS commit
    [BiphasicBoard.brd, BiphasicBoard.sch]
2014-05-19 Changed directory structure
    [BiphasicBoard.brd, BiphasicBoard.sch]
2014-05-19 Editted design
    [BiphasicBoard.brd, BiphasicBoard.sch]
2014-05-20 Updated Library Parts
    [BiphasicBoard.brd, BiphasicBoard.sch]
2014-05-20 Updated Board
    Updated the board design to comply with the DRC of Seed_DRU
    [BiphasicBoard.brd]
2014-06-20 Version 1.0 Changes 1) Dual channel biphasic current output; 2) LED to indicate power supply status.
    [BiphasicBoardv2.brd, BiphasicBoardv2.sch]
2014-06-20 Version 1.1 Changes 1) Added a voltage divider to measure power supply level 2) Removed impedence measurement in one of the biphasic current output channels
    [BiphasicBoardv2.brd, BiphasicBoardv2.sch]
2014-06-20 Made a few cosmetic changes
    [BiphasicBoard.brd, BiphasicBoardv2.brd, BiphasicBoardv2.sch]
2014-06-20 Smashed a bunch of parts. Changed font sizes to 25 mil, 15% ratio
    [BiphasicBoardv2.brd]
2014-06-20 Added values layers to cam silkscreen
2014-06-20 Fixed error just introduced in CAM job. Further added values. Labels for power.
    [BiphasicBoardv2.brd, BiphasicBoardv2.sch]
2014-07-04 1) Corrected resistor name&values; 2) Added resistor for LED.
    [BiphasicBoardv2.brd, BiphasicBoardv2.sch]
2014-07-06 Smashed LED resistor, changed font to 25/16%/Vector, rounded corners.
    [BiphasicBoardv2.brd, BiphasicBoardv2.sch]
2014-07-09 Moved some wires around to make ground plane larger.
    [BiphasicBoardv2.brd]
2014-07-17 MSP code to use with version 1 pcb.
2014-07-17 Code to use with version 1 pcb
2014-07-20 7/20/2014 B.M. Fixed code and comments.
    [DS4432_TS3A4751_LED.c]
2014-11-06 Updated randomized version of the DBS board (c code, not tested). 11/06/2014
2015-05-08 Added single channel stimulator
    [RatDBS.brd, RatDBS.sch]
2015-07-08 Changed colors and put values onto PCB
    [RatDBS.brd]
2015-08-16 Changed some colors and labels, changed code directory structure, and added docs for RF430
    [RatDBS.brd, RatDBS.sch]
2015-08-26 Moved gitignore into PCBs directory and repaired Seeed CAM file for EAGLE 7
2015-08-26 Added NFC-controlled PCB and I2C command list
    [RatDBS.brd, RatDBS.sch]
2015-09-05 Added code for NFC PCB firmware. Compiles (but untested). No NFC hooks yet.
2015-09-05 Found bug in PCB - switch matrix not wired up correctly. Fixed, and added interrupt and reset connections to MSP430
    [RatDBS.brd, RatDBS.sch]
2015-09-07 Fixed I2C communication so that "hello world" is now being pushed to NFC device. Was a royal pain. Had to give up on polling I2C because stop condition was generated too early so last byte always got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
    [BatteryStatus.c, I2C.c, Main.c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]
2015-09-08 Reformatted I2C code and updated ISR declarations
2015-09-10 Switched to external NDEF record type to allow for binary data. Changed app and firmware. Working.
2015-09-11 Reformatted globals so that DeviceData is now a global structure that corresponds to NDEF message
2015-09-11 More deletions. Also fixed memory leak bug in I2C string.
    [NFCInterface.c, NFCInterface.h]
2015-09-11 Wowser. Finally figured out I2C receive, transmit, and transmit/receive.
2015-09-15 Reasonable battery life. Still haven't tested switches or current source yet.
2015-09-18 Created board test CCS/Energia project. More changes in android app
2015-09-18 Added CCS files for BoardTest.
2015-09-19 Added some hacks that appear to fix transitions from programming RF430 to DS4432
    [I2C.c, Main.c, NFCInterface.c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]
2015-09-23 Two more boards with integrated CR2032 battery holders. More doc pds, improved code.
    [RatDBS-2032-2Variant.brd, RatDBS-Compact2032Battery.brd, RatDBS-Compact2032Battery.sch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]
2015-09-23 Changed PowerBudget to README
2015-09-23 Fixed board errors that were fixed in panelized version
    [RatDBS-Compact2032Battery.brd, RatDBS-Plastic2032Battery.brd]
2015-09-24 Made I2C 333 kHz instead of 100
2015-09-25 Cleaned up file/directory structure for PCBs
    [BiphasicBoard.brd, BiphasicBoard.sch, BiphasicBoardv2.brd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]
2015-09-25 Rearranged directory structure and added Board.h with constants which depend on board revision
2015-09-26 Updated README about power consumption
    removed some
2015-09-28 Added jitter to firmware (now version 5) and updated android app. also fixed some bugs, such as up/back issue
    [BatteryStatus.c, Board.h, I2C.c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]
2015-10-02 Reordered some code and fixed bug so that edit toggle is disabled by default.
    [MainActivity.java]
2015-10-05 Switched all settings to dropdown menus
2015-10-05 Removed excess dialog stuff after switching to spinners. Fixed onsave/onrestore to properly deal with enable switch toggle.
    [MainActivity.java]
2015-10-05 Fixed bug where jitter was not accurate. Now subtrace half of jitter max before adding random value
    [BatteryStatus.c, Main.c, NFCInterface.c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]
2015-10-09 Switched I2C back to 100 kHz and fixed bug where unsigned int timer counters could underflow
    [I2C.c, Main.c, NFCInterface.c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]
2015-10-12 Added an error state until NFC is read correctly.
    [RatDBS-Compact2032Battery.brd, RatDBS-Compact2032Battery.sch]
2015-10-16 Changed micro to milli in jitter value dropdown menu
2015-10-16 Changes made in order to get stimulation working with new modules. (1) Had to properly assign pins for switch matrix. (2) Had to boost master clock to 8 MHz so that stim interrupt would actually be a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
    [Board.h, I2C.c, Main.c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]
2016-06-03 Added supporter pngs for website and updated PCBs.
    [RatDBS-CompactWithInductor.brd, RatDBS-CompactWithInductor.sch, RatDBS-Plastic2032Battery-WithRegulator.brd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]
2017-02-27 Updated PCB manufacturing
    [RatDBS-Plastic2032Battery-WithRegulator.brd, RatDBS-Plastic2032Battery-WithRegulator.sch]
2017-07-03 Updated primary design and added two component (battery-on-separate-pcb) version)
    [RatDBS-BatteryBoard.brd, RatDBS-BatteryBoard.sch, RatDBS-Compact2032Battery.brd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]
2017-09-14 Adds low battery notification LED. Implements jitter. Updates voltage calculation for dual cell stimulator.
    [BatteryStatus.c, Board.h, Main.c]
2017-10-18 Added google play APK to repository
    Google play downloads outside of the US are limited. This APK file can be manually added to android devices and installed through the file manager. Tested with OI File Manager.
2017-10-23 Added resistor values for voltage divider and LEDs. Labeled preferred 332 inductor antenna and CANT values.
    [RatDBS-TrackBattery.brd, RatDBS-TrackBattery.sch]
2018-10-13 Added solidparts and STLs for headcap assembly. Contains readme and render for construction.
    [cone_stereotax_adapter.SLDPRT, cone_stereotax_adapter.STL, lid_for_stimulator.SLDPRT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]
2019-01-08 Added estimated power notebook
    [PowerNotebook.xlsx]

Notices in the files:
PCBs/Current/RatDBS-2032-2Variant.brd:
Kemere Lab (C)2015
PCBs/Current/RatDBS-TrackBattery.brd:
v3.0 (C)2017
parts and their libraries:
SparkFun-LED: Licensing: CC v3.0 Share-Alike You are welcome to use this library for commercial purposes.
